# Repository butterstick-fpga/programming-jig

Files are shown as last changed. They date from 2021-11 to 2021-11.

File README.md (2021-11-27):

# ButterStick Programming-jig

A simple FT232H based programming jig for the ButterStick.

---

## What is it

A simple jig made from PCBs that connects to a ButterStick with pogo-pins.

The board supports 
 - Programming/comms over JTAG.
 - Voltage sensing via an SPI ADC connected to the FT232H's I/O pins.

## Render

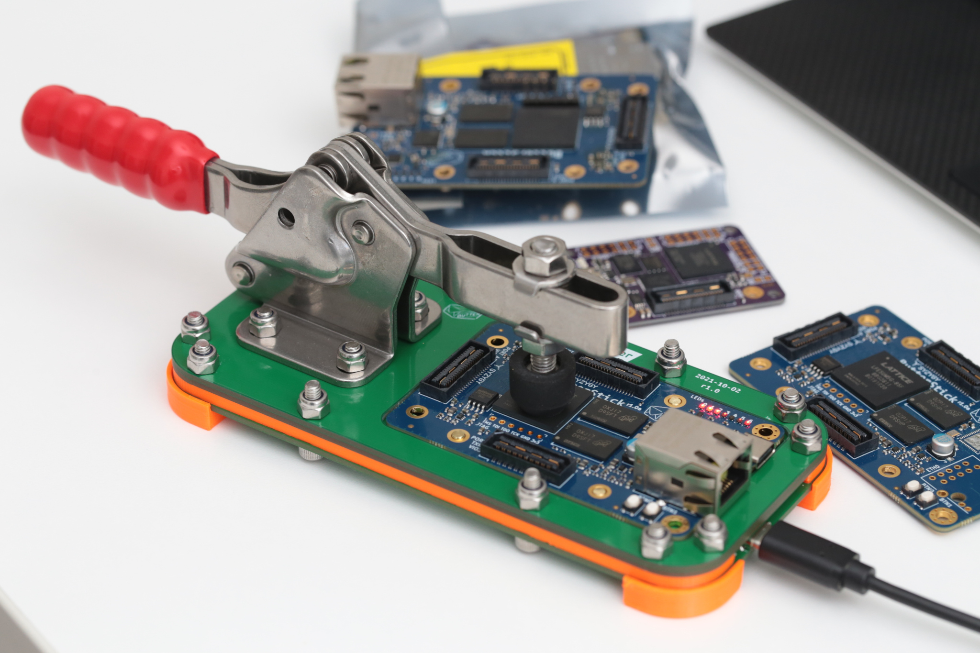
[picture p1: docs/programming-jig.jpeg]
Finished PCBs


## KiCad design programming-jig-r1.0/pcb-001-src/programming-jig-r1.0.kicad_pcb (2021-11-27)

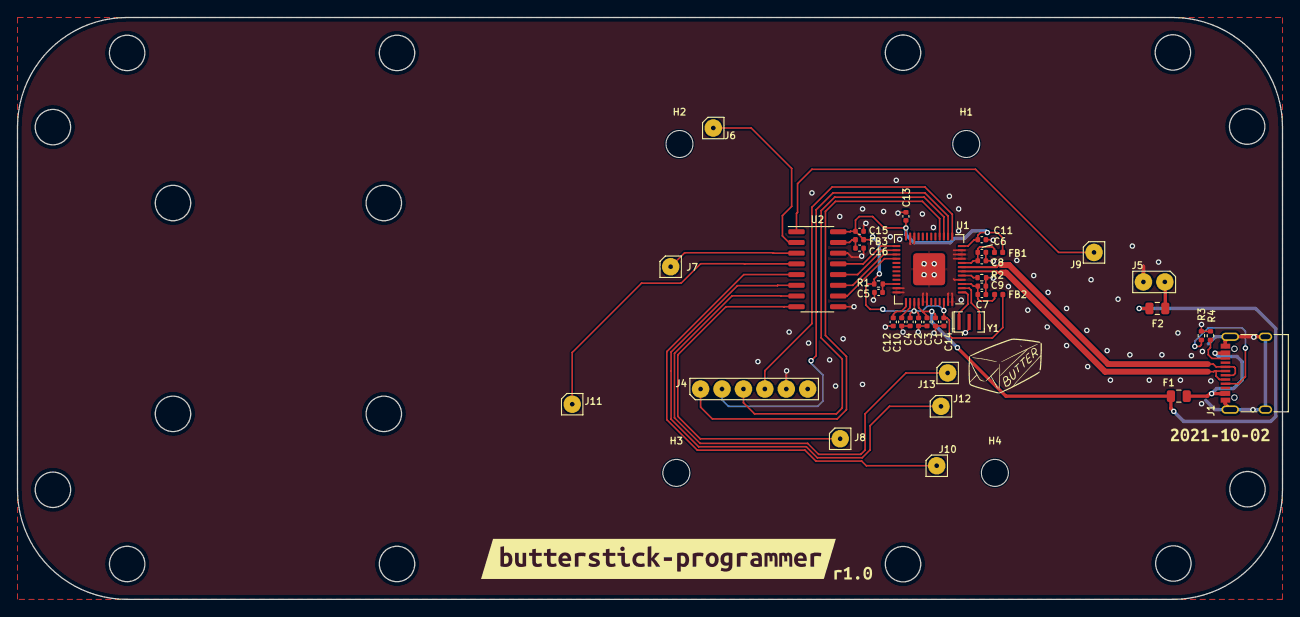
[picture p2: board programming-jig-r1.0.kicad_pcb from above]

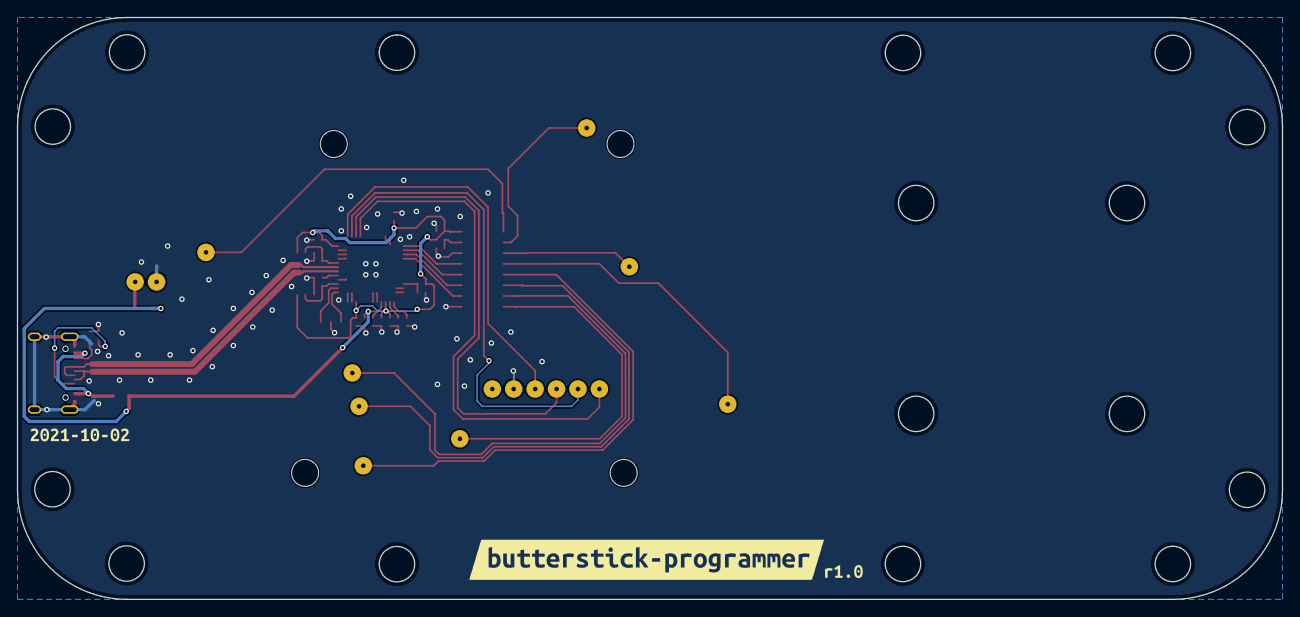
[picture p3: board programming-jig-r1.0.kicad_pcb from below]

Board: 2 copper layers, 150.0 x 69.0 mm, 49 parts (3 on the bottom side), 34 nets.

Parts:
C1, C2, C6, C7: 4.7uF; C_0402_1005Metric
C3, C4, C8, C9, C10, C11, C12, C13, C14, C15, C16: .1uF; C_0402_1005Metric
C5: 0.1uF; C_0402_1005Metric
F1, F2: Polyfuse_Small; Fuse_0805_2012Metric
FB1, FB2, FB3: Ferrite_Bead_Small; L_0402_1005Metric
H1, H2, H3, H4: MountingHole; MountingHole_3.2mm_M3_DIN965
J1: USB_C_Receptacle_USB2.0; USB_C_Receptacle_XKB_U262-16XN-4BVC11
J4: Conn_01x06_Male; 821-22-006-10-004101
J5: Conn_01x02_Male; 821-22-002-10-004101
J6, J7, J8, J9, J10, J11, J12, J13: Conn_01x01_Male; 0906-4-15-20-75-14-11-0
R1: 4.7K; R_0402_1005Metric
R2: 12K; R_0402_1005Metric
R3, R4: 5K1; R_0402_1005Metric
U1: FT232HQ; QFN-48-1EP_8x8mm_P0.5mm_EP6.2x6.2mm
U2: MCP3008; SOIC-16_3.9x9.9mm_P1.27mm
Y1: Resonator; Resonator_SMD_Murata_CSTxExxV-3Pin_3.0x1.1mm
kibuzzard-615A738C, kibuzzard-615A738C#2: G***; kibuzzard-615A738C
kibuzzard-615A7324, kibuzzard-615A7324#2: G***; kibuzzard-615A7324
kibuzzard-615A7371, kibuzzard-615A7371#2: G***; kibuzzard-615A7371

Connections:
+3.3VA: C2.1, C4.1, C11.1, C13.1, C14.1, C15.1, FB1.2, FB2.2, FB3.2, R1.2, U1.12 (VCCIO), U1.24 (VCCIO), U1.39 (VCCD), U1.46 (VCCIO), U2.16 (Vdd)
+5V: C1.1, C3.1, F1.1, F2.1, U1.40 (VREGIN)
/JTAG_TCK: J4.4, U1.13 (ADBUS0)
/JTAG_TDI: J4.2, U1.14 (ADBUS1)
/JTAG_TDO: J4.3, U1.15 (ADBUS2)
/JTAG_TMS: J4.1, U1.16 (ADBUS3)
/USB_D+: J1.A6 (D+), J1.B6 (D+), U1.7 (DP)
/USB_D-: J1.A7 (D-), J1.B7 (D-), U1.6 (DM)
/VCCA: C12.1, U1.37 (VCCA)
/VCORE: C10.1, U1.38 (VCCCORE)
GND: C1.2, C2.2, C3.2, C4.2, C5.2, C6.2, C7.2, C8.2, C9.2, C10.2, C11.2, C12.2, C13.2, C14.2, C15.2, C16.2, J1.A1 (GND), J1.A12 (GND), J1.B1 (GND), J1.B12 (GND), J1.S1 (SHIELD), J4.5, J5.2, R2.1, R3.2, R4.2, U1.4 (AGND), U1.9 (AGND), U1.10 (GND), U1.11 (GND), U1.22 (GND), U1.23 (GND), U1.35 (GND), U1.36 (GND), U1.41 (AGND), U1.42 (TEST), U1.47 (GND), U1.48 (GND), U1.49 (GND), U2.9 (DGND), U2.14 (AGND), Y1.2
unnamed: C5.1, R1.1, U1.34 (~RESET)
unnamed: C6.1, C8.1, FB1.1, U1.8 (VPLL)
unnamed: C7.1, C9.1, FB2.1, U1.3 (VPHY)
unnamed: C16.1, FB3.1, U2.15 (Vref)
unnamed: F1.2, J1.A4 (VBUS), J1.A9 (VBUS), J1.B4 (VBUS), J1.B9 (VBUS)
unnamed: J1.A5 (CC1), R3.1
unnamed: J1.B5 (CC2), R4.1
unnamed: F2.2, J5.1
unnamed: R2.2, U1.5 (REF)
unnamed: U1.1 (XCSI), Y1.1
unnamed: U1.2 (XCSO), Y1.3
unnamed: U1.25 (ACBUS1), U2.13 (CLK)
unnamed: U1.26 (ACBUS2), U2.12 (Dout)
unnamed: U1.27 (ACBUS3), U2.11 (Din)
unnamed: U1.28 (ACBUS4), U2.10 (~CS/SHDN)
unnamed: J9.1, U2.1 (CH0)
unnamed: J6.1, U2.2 (CH1)
unnamed: J7.1, U2.3 (CH2)
unnamed: J11.1, U2.4 (CH3)
unnamed: J10.1, U2.5 (CH4)
unnamed: J12.1, U2.6 (CH5)
unnamed: J13.1, U2.7 (CH6)
unnamed: J8.1, U2.8 (CH7)
